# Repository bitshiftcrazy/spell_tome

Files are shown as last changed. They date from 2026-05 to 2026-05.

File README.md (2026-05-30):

# Spell Tome PCB

<p align="center">
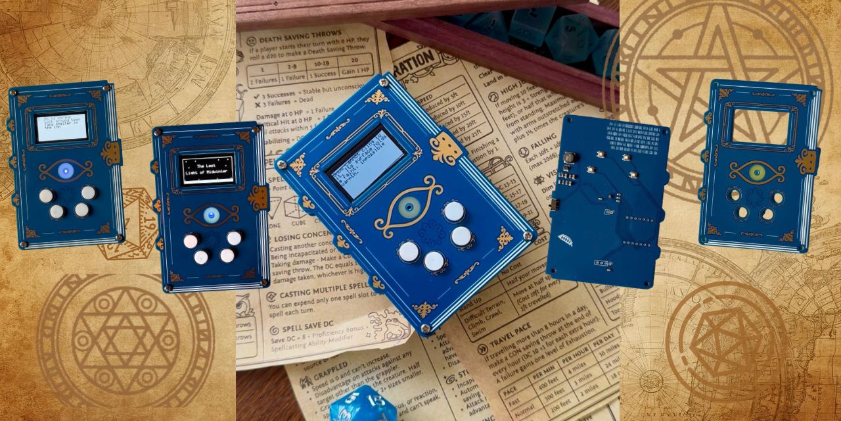
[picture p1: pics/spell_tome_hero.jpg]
  
</p>

A handheld fantasy-themed PCB spell tome designed for tabletop RPGs and other shenanigans.

The Spell Tome is a sandwiched, book-like PCB build consisting of
a functional electronics PCB and a decorative top PCB.
Originally it was designed as a magical artifact for a custom text adventure and small games.

Right now it's evolving into anything that can be done with a tiny OLED and 4 buttons (stay tuned!).

---

## Features

- Handheld layered PCB construction
- Decorative top PCB with silkscreen and copper artwork
- Book-label-style OLED display
- RGB status eye staring at your soul
- Push buttons
- Powered by 2x AAA batteries
- Designed around the Seeed Studio XIAO RP2040
- Custom firmware for text adventures and other games (currently under cleanup, coming soon)

---

## Gallery

<p align="center">
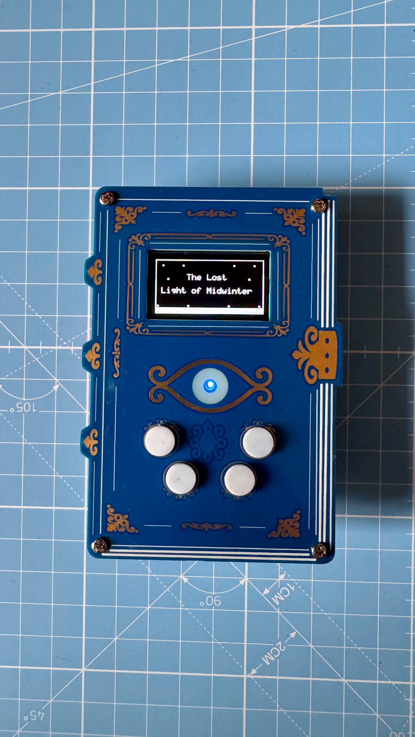
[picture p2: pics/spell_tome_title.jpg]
  
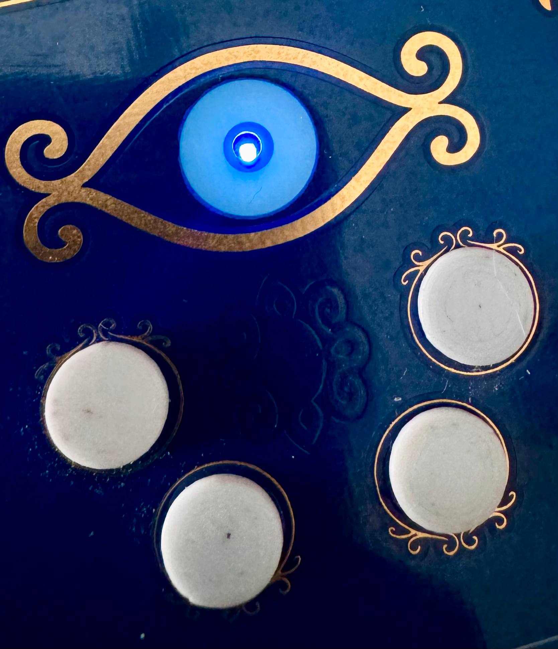
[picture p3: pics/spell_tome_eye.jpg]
  
</p>

<p align="center">
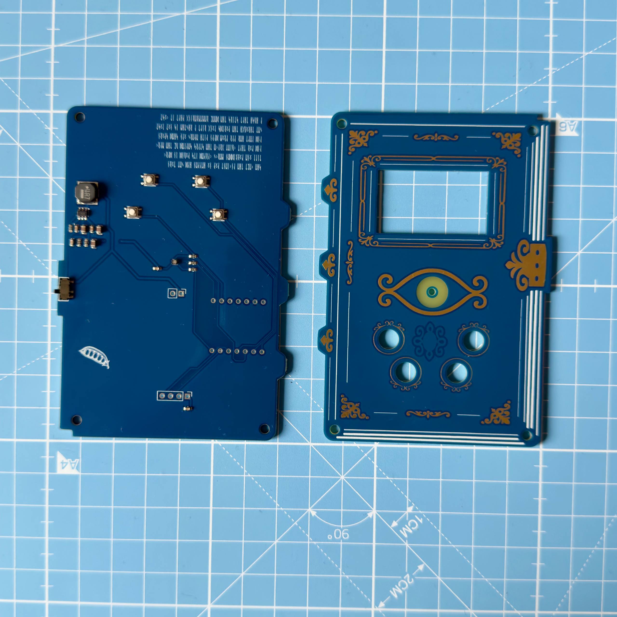
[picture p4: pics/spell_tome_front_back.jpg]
  
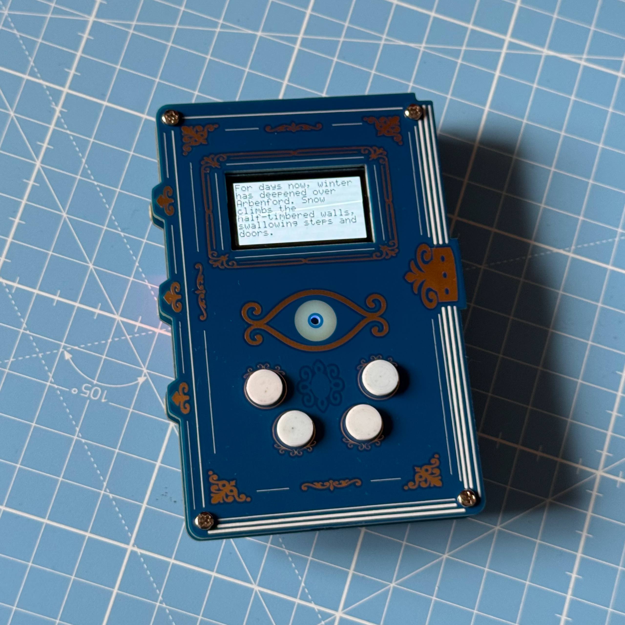
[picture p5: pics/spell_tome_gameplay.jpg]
  
</p>

---

## Hardware Overview

<p align="center">
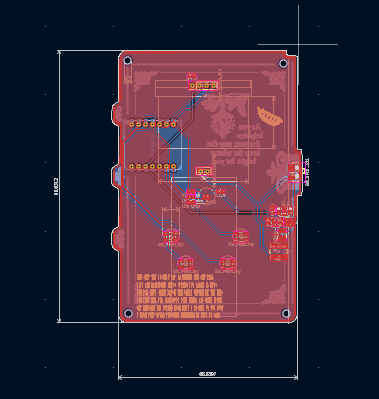
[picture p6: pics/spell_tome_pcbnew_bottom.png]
  
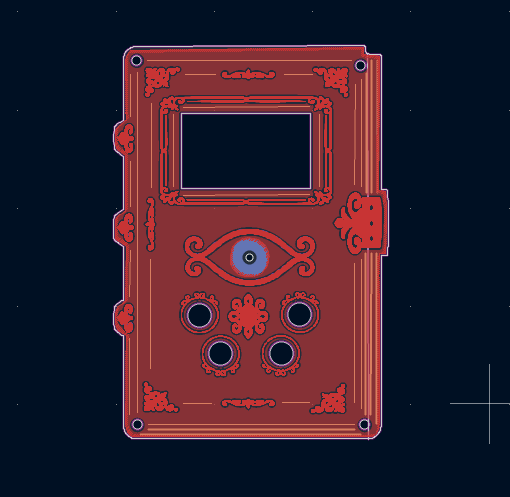
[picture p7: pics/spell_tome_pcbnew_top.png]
  
</p>

The Spell Tome is designed around a Seeed Studio XIAO RP2040 to make it easy to customise, reprogram, and repurpose. It consists of two separate PCBs that together form a small handheld device, no additional case needed.

### Bottom PCB

The bottom PCB holds all the electronics, meaning the schematics only refer to the bottom PCB. Buttons and RGB LED parts are flat so that the handheld stays slim overall.

<p align="center">
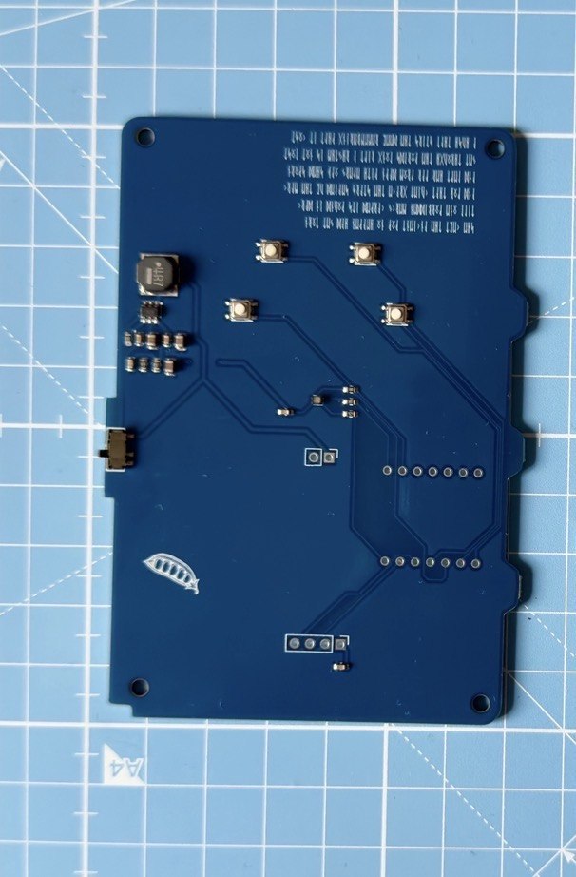
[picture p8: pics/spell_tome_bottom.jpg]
  
</p>

### Top PCB

The top PCB functions as a decorative cover for the handheld. It has an eye-shaped keepout zone so the status LED's light shines through. Very magic. Much wow.

It also has cutouts for 4 3D printed buttons.

<p align="center">
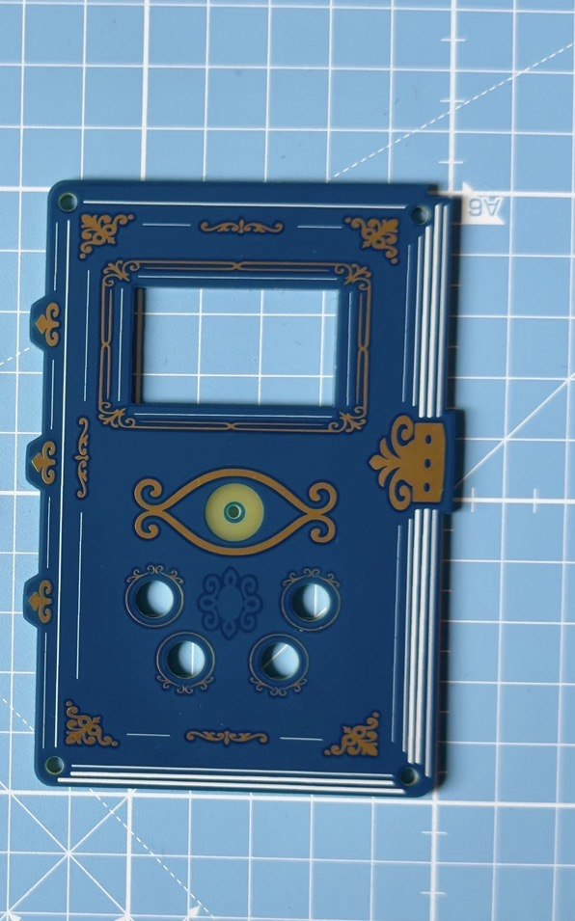
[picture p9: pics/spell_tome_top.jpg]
  
</p>

---

## Main Components

The parts selection is mainly influenced by "I have this at home already" and "I want people to be able to easily assemble and program it":

- Seeed Studio XIAO RP2040 microcontroller
- 1.3" OLED display
- MCP1640 boost converter
- RGB status LED
- 4x tactile push buttons
- Power slide switch
- 2x AAA battery holder
- 4x 3D printed button caps
- 4x spacers and screws (ideally golden, for the vibe)

Of course the project also uses standard components such as
resistors, capacitors, and passive power circuitry. You'll find them and their respective values in the BOM files in:

```text
fabrication/bom/
```

---

## Assembly

<p align="center">
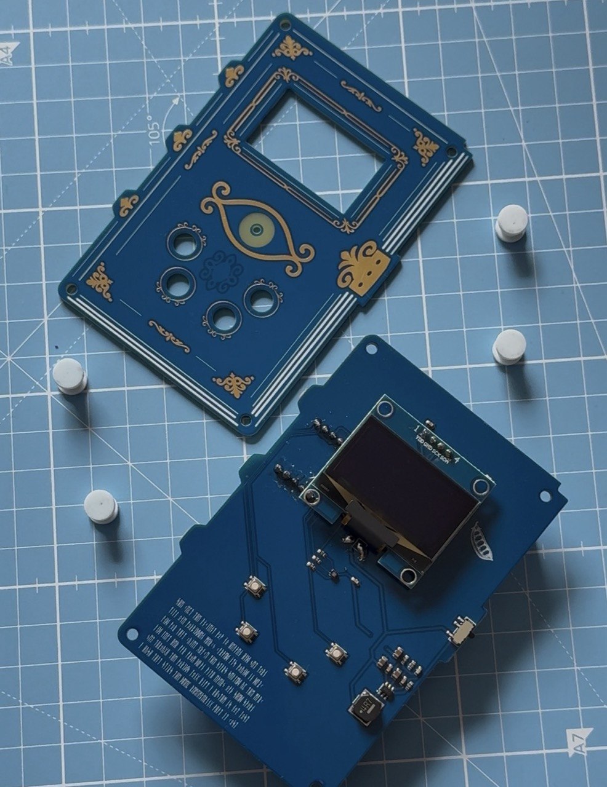
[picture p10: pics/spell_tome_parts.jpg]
  
</p>

### PCB Stackup

Since the Spell Tome uses a layered PCB construction, you'll need to fit these parts together:

1. Bottom electronics PCB
2. Printed button elements
3. Decorative top PCB
4. Battery holder

To assemble the Tome you'll need M2.5 screws and spacers/standoffs (6 mm worked well for me here).

Detailed soldering instructions follow.

Assuming you already soldered the parts:

1. Screw the standoff to the bottom PCB (screw on the outward-facing side, standoff inside)
2. Put the button-shaped button parts through the top PCB's holes and secure them with the little 3D printed rings
3. Put the cover on top of the standoffs on the bottom PCB and test the buttons a little to find a good distance before screwing it on (you can also adjust this later with something pointy)
4. Glue the battery holder to the back where it feels comfortable and make sure to secure the wires with a little glue as well

#### Mechanical Button Parts

3D printable parts are available in:

```text
mechanical/
```

Print the buttons without supports.

### Assembly Notes

- you can find golden screws that pass the vibe check if you look for jewellery screws
- I printed the buttons in white PLA, but it's probably more comfy to use TPU and prettier with something shiny
- depending on how thick you want that thing to be, you can also use longer standoffs and put the batteries between the sandwich layers

---

## Repository Structure

```text
spell_tome/
├── artwork/        # Source artwork and SVG files
├── fabrication/    # BOMs and fabrication outputs
├── libraries/      # Local KiCad symbol and footprint libraries
├── mechanical/     # 3D printable parts
├── pics/           # Images and renders
├── *.kicad_*       # Main KiCad project files
└── README.md
```

---

## Firmware

Firmware was hacked together in one long weekend and is currently under cleanup (guess "a little messy" is fine for personal projects, "wtf even is that" is not ;)) and will be published in this repo soon.

Features:
- the cringiest text adventure you'll ever play
- impractical mini games
- the mysterious blood moon side quest

---

## Fabrication

Gerbers and manufacturing files can be generated directly from the KiCad project files. The current Gerbers are the tested and working version.

Please make sure to regenerate them before sending something to fabrication, I cannot be trusted to remember to do this after every change I make.

Pre-generated fabrication outputs belong and are available in:

```text
fabrication/gerbers/
```

---

## Color inspo

<p align="center">
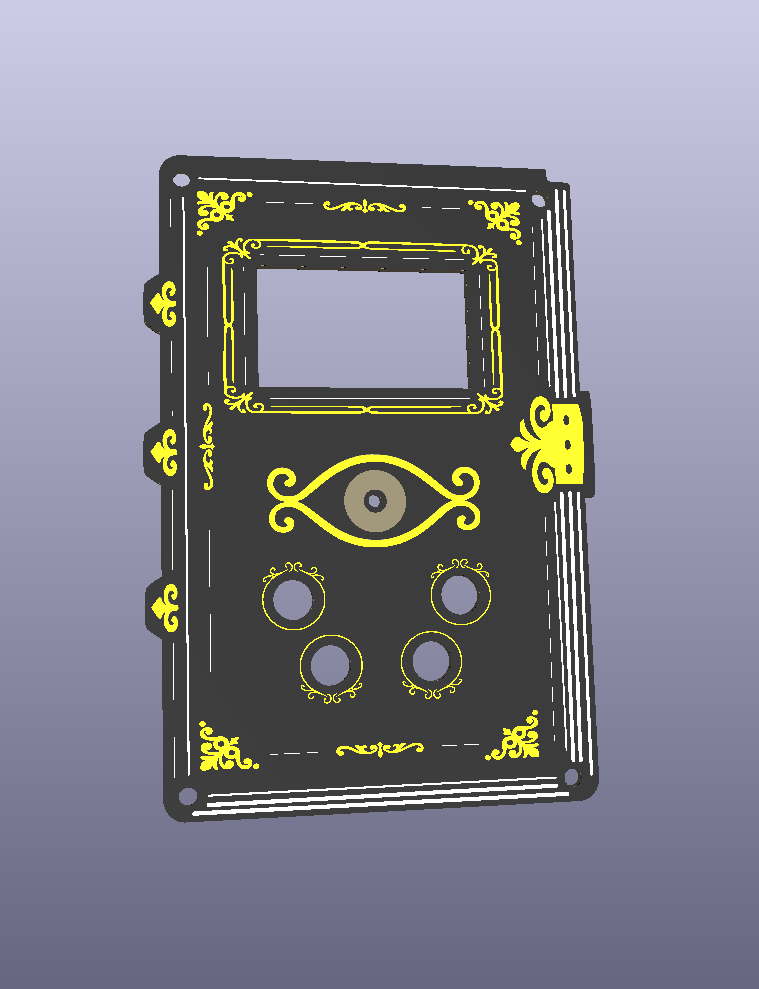
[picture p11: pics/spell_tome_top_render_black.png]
  
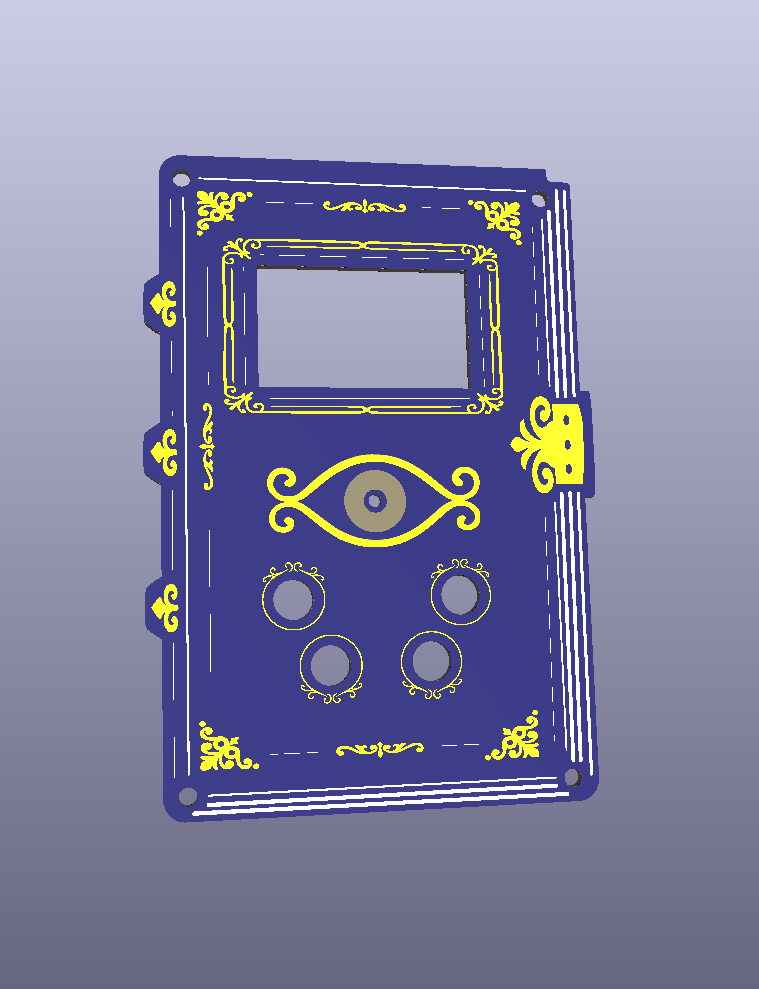
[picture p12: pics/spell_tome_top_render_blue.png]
  
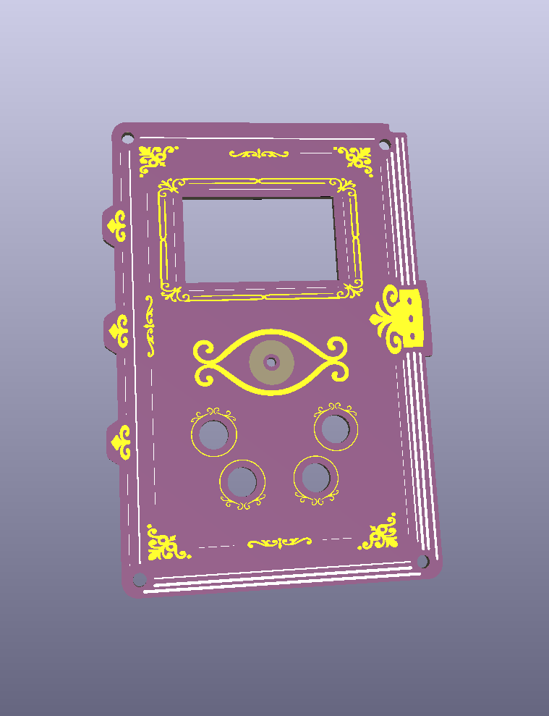
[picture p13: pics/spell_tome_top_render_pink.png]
  
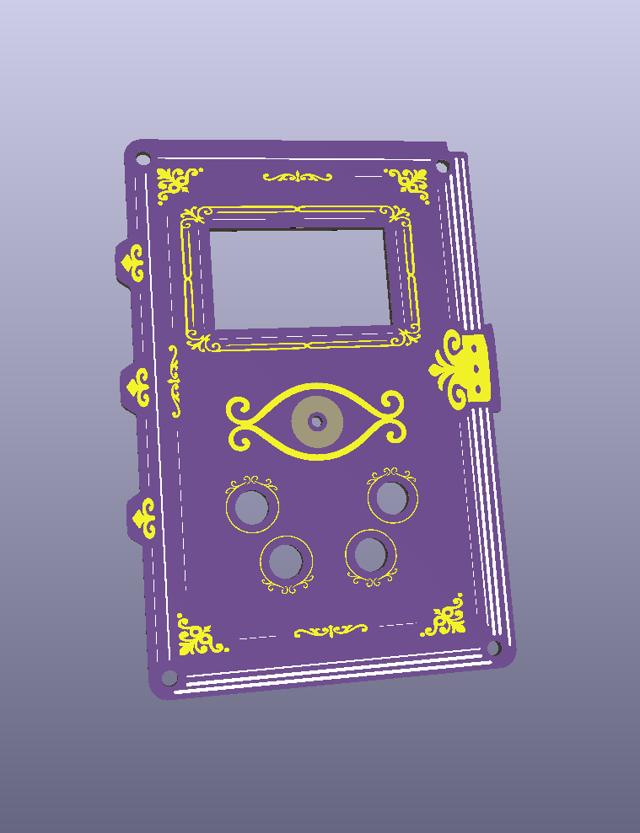
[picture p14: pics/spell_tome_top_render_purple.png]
  
</p>

## Further Reading
- [Hackster: This Open Source RP2040 Development Board Looks Like a Magic Spellbook](https://www.hackster.io/news/this-open-source-rp2040-development-board-looks-like-a-magic-spellbook-52a614f74b81)

## License

Hardware design files are licensed under the CERN Open Hardware Licence
Version 2 - Strongly Reciprocal (CERN-OHL-S-2.0).

See the `LICENSE` file for details.

Copyright (c) 2026 miss.molerat

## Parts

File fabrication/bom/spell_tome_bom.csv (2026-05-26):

Reference | Qty | Value | DNP | Exclude from BOM | Exclude from Board | Footprint | Datasheet | LCSC
C1(CIN)1,C3(COUT)1,C3(COUT)2 | 3 | 10uF |  |  |  | Capacitor_SMD:C_0805_2012Metric | ~ | C15850
C2(CIN_HF)1,C4(COUT_HF)1,C5(C_RGB)1,C7(C_OLED)1 | 4 | 0.1uF |  |  |  | Capacitor_SMD:C_0603_1608Metric | ~ | C14663
C6(Cff)1 | 1 | 47pF |  |  |  | Capacitor_SMD:C_0603_1608Metric | ~ | C94904
D1 | 1 | LED_RABG |  |  |  | tome:LED-ARRAY-SMD_4P-L1.6-W1.5-TL_NH-B1515RGBA | ~ | C2874115
J1 | 1 | Conn_01x04_Pin |  |  |  | Connector_PinHeader_2.54mm:PinHeader_1x04_P2.54mm_Vertical | ~
J2 | 1 | Conn_01x02_Pin |  |  |  | Connector_PinHeader_2.54mm:PinHeader_1x02_P2.54mm_Vertical | ~
L1 | 1 | L |  |  |  | tome:IND-SMD_L6.0-W6.0_NR6028T2R2N | ~
R1(red)1 | 1 | 470 Ohm |  |  |  | Resistor_SMD:R_0603_1608Metric | ~ | C23179
R2(green)1,R3(blue)1 | 2 | 150 Ohm |  |  |  | Resistor_SMD:R_0603_1608Metric | ~ | C22808
R4(R_top)1 | 1 | 680kOhm |  |  |  | Resistor_SMD:R_0603_1608Metric | ~ | C25822
R5(R_bottom)1 | 1 | 390kOhm |  |  |  | Resistor_SMD:R_0603_1608Metric | ~ | C23150
R6 | 1 | R |  |  |  | Resistor_SMD:R_0603_1608Metric | ~ | C25803
SW1,SW3,SW4,SW5 | 4 | SW_Push_my |  |  |  | tome:SW-SMD_4P-L3.4-W3.4-P2.15-LS4.2 | ~ | C596271
SW2 | 1 | SW_SPDT_321 |  |  |  | tome:SW-SMD_SSSS810701 | ~ | C97433
U1 | 1 | XIAO-RP2040-DIP |  |  |  | Seeed Xiao RP2040:XIAO-RP2040-DIP
U2 | 1 | MCP1640x-xCHY |  |  |  | tome:SOT-23-6_L2.9-W1.6-P0.95-LS2.8-BR | http://ww1.microchip.com/downloads/en/DeviceDoc/20002234D.pdf | C44365

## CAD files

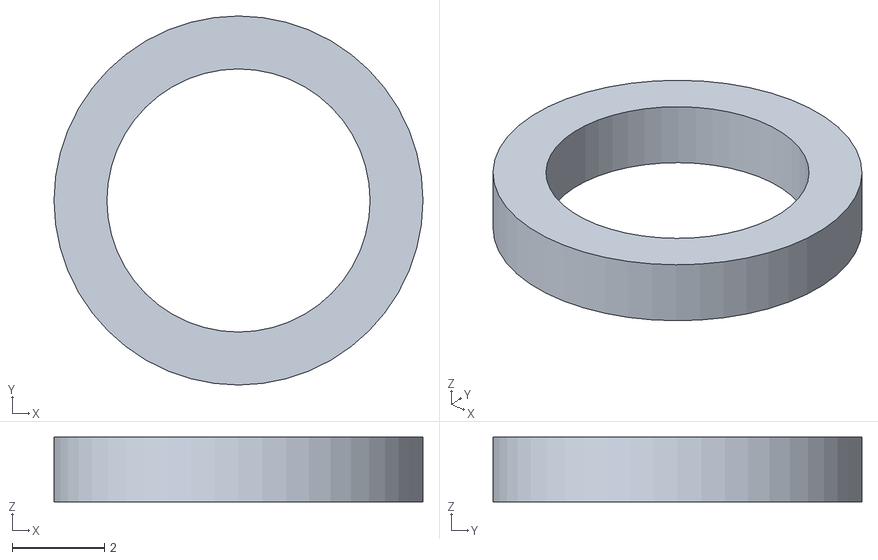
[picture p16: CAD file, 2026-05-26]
mechanical/spell_tome_button.stl
8.00 x 8.00 x 1.40

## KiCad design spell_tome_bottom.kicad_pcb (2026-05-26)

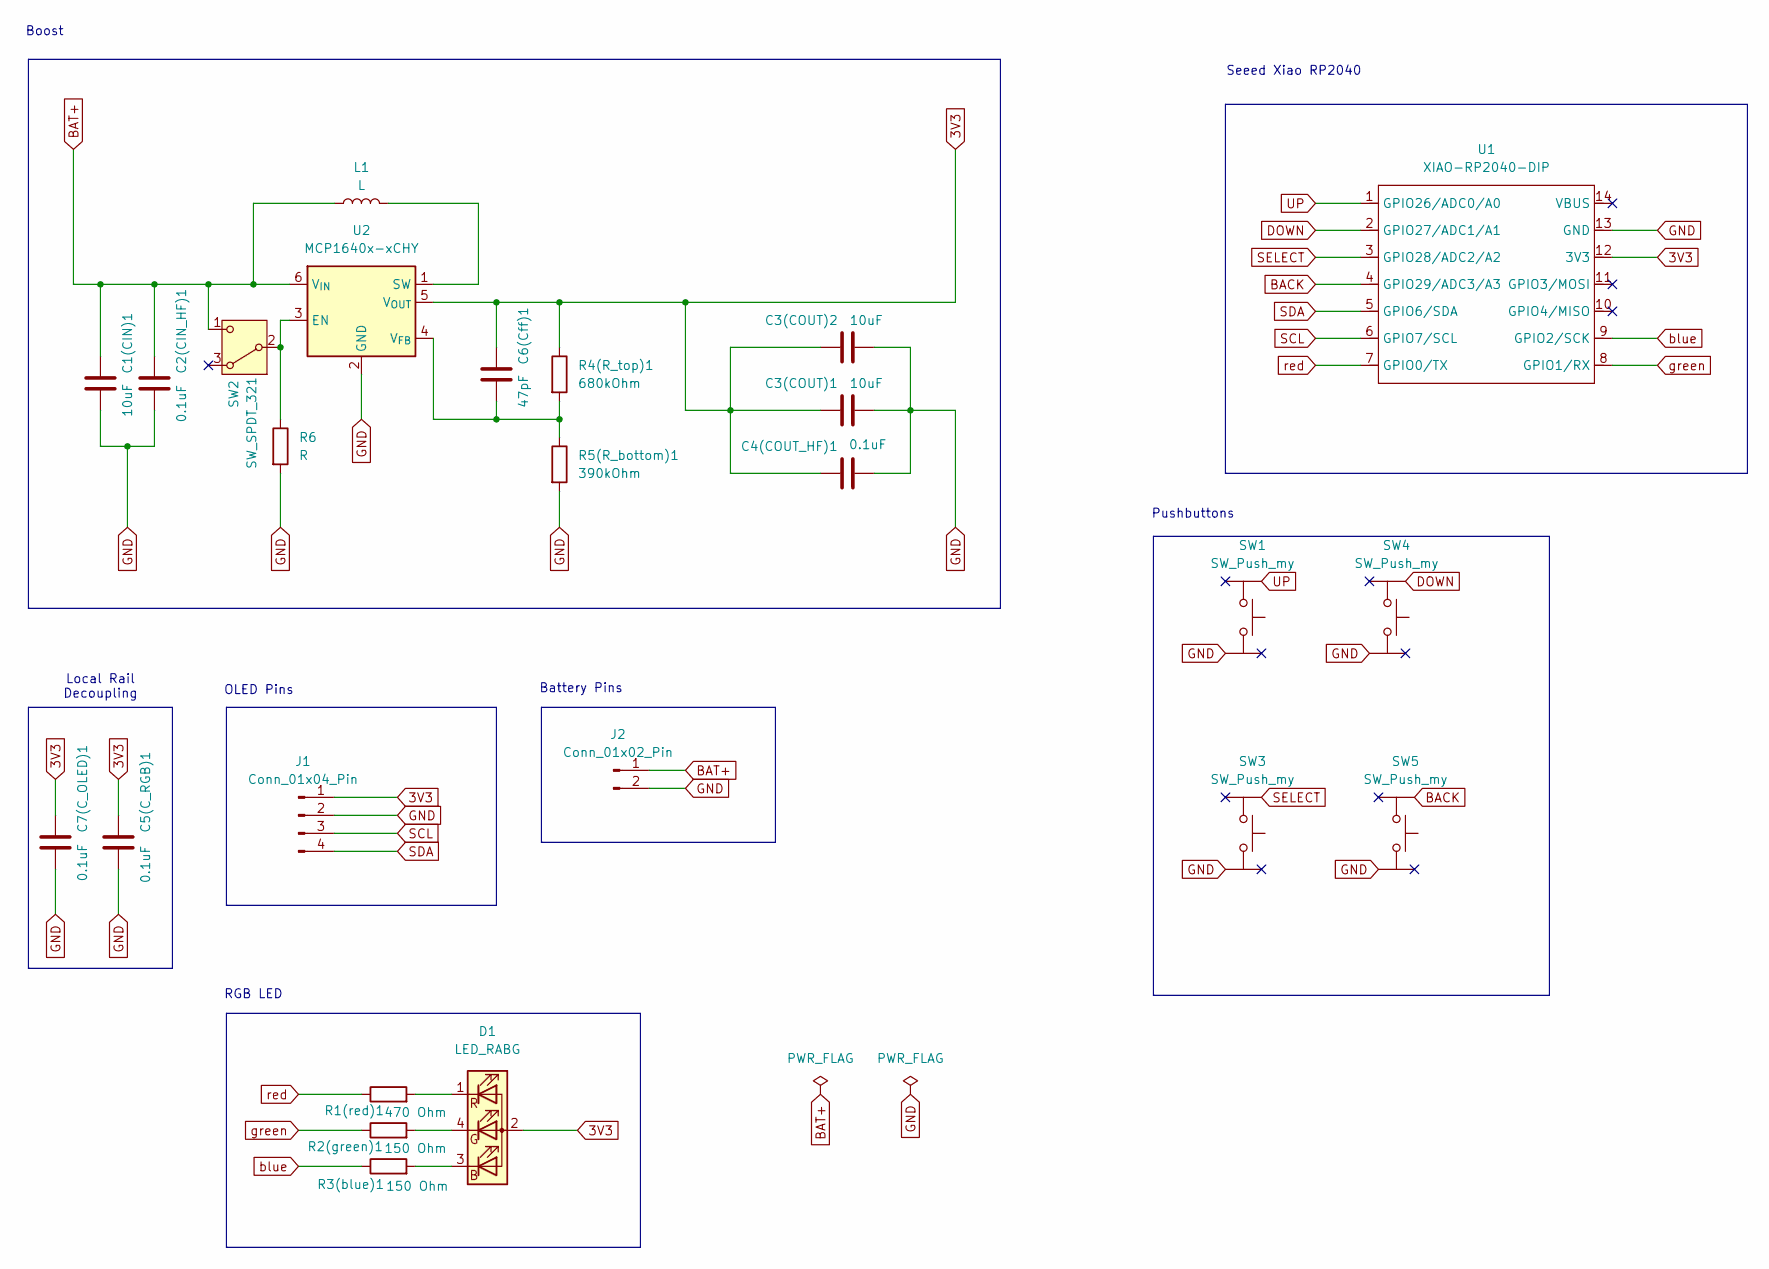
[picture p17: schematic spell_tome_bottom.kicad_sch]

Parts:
C1(CIN)1, C3(COUT)1, C3(COUT)2: 10uF; C_0805_2012Metric; LCSC C15850
C2(CIN_HF)1, C4(COUT_HF)1, C5(C_RGB)1, C7(C_OLED)1: 0.1uF; C_0603_1608Metric; LCSC C14663
C6(Cff)1: 47pF; C_0603_1608Metric; LCSC C94904
D1: LED_RABG; LED-ARRAY-SMD_4P-L1.6-W1.5-TL_NH-B1515RGBA; LCSC C2874115
J1: Conn_01x04_Pin; PinHeader_1x04_P2.54mm_Vertical
J2: Conn_01x02_Pin; PinHeader_1x02_P2.54mm_Vertical
L1: L; IND-SMD_L6.0-W6.0_NR6028T2R2N
R1(red)1: 470 Ohm; R_0603_1608Metric; LCSC C23179
R2(green)1, R3(blue)1: 150 Ohm; R_0603_1608Metric; LCSC C22808
R4(R_top)1: 680kOhm; R_0603_1608Metric; LCSC C25822
R5(R_bottom)1: 390kOhm; R_0603_1608Metric; LCSC C23150
R6: R; R_0603_1608Metric; LCSC C25803
SW1, SW3, SW4, SW5: SW_Push_my; SW-SMD_4P-L3.4-W3.4-P2.15-LS4.2; LCSC C596271
SW2: SW_SPDT_321; SW-SMD_SSSS810701; LCSC C97433
U1: XIAO-RP2040-DIP
U2: MCP1640x-xCHY; SOT-23-6_L2.9-W1.6-P0.95-LS2.8-BR; LCSC C44365

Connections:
3V3: C3(COUT)1.1, C3(COUT)2.1, C4(COUT_HF)1.1, C5(C_RGB)1.1, C6(Cff)1.1, C7(C_OLED)1.1, D1.2 (A), J1.1, R4(R_top)1.1, U1.12 (3V3), U2.5 (V_{OUT})
BACK: SW5.1, U1.4 (GPIO29/ADC3/A3)
BAT+: C1(CIN)1.1, C2(CIN_HF)1.1, J2.1, L1.1, SW2.1 (C), U2.6 (V_{IN})
DOWN: SW4.1, U1.2 (GPIO27/ADC1/A1)
GND: C1(CIN)1.2, C2(CIN_HF)1.2, C3(COUT)1.2, C3(COUT)2.2, C4(COUT_HF)1.2, C5(C_RGB)1.2, C7(C_OLED)1.2, J1.2, J2.2, R5(R_bottom)1.2, R6.2, SW1.4, SW3.4, SW4.4, SW5.4, U1.13 (GND), U2.2 (GND)
unnamed: D1.3 (BK), R3(blue)1.2
unnamed: D1.4 (GK), R2(green)1.2
unnamed: D1.1 (RK), R1(red)1.2
unnamed: R6.1, SW2.2 (B), U2.3 (EN)
unnamed: L1.2, U2.1 (SW)
unnamed: C6(Cff)1.2, R4(R_top)1.2, R5(R_bottom)1.1, U2.4 (V_{FB})
SCL: J1.3, U1.6 (GPIO7/SCL)
SDA: J1.4, U1.5 (GPIO6/SDA)
SELECT: SW3.1, U1.3 (GPIO28/ADC2/A2)
UP: SW1.1, U1.1 (GPIO26/ADC0/A0)
blue: R3(blue)1.1, U1.9 (GPIO2/SCK)
green: R2(green)1.1, U1.8 (GPIO1/RX)
red: R1(red)1.1, U1.7 (GPIO0/TX)

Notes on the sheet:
OLED Pins
RGB LED
Battery Pins
Pushbuttons
Boost
Seeed Xiao RP2040
Local Rail Decoupling

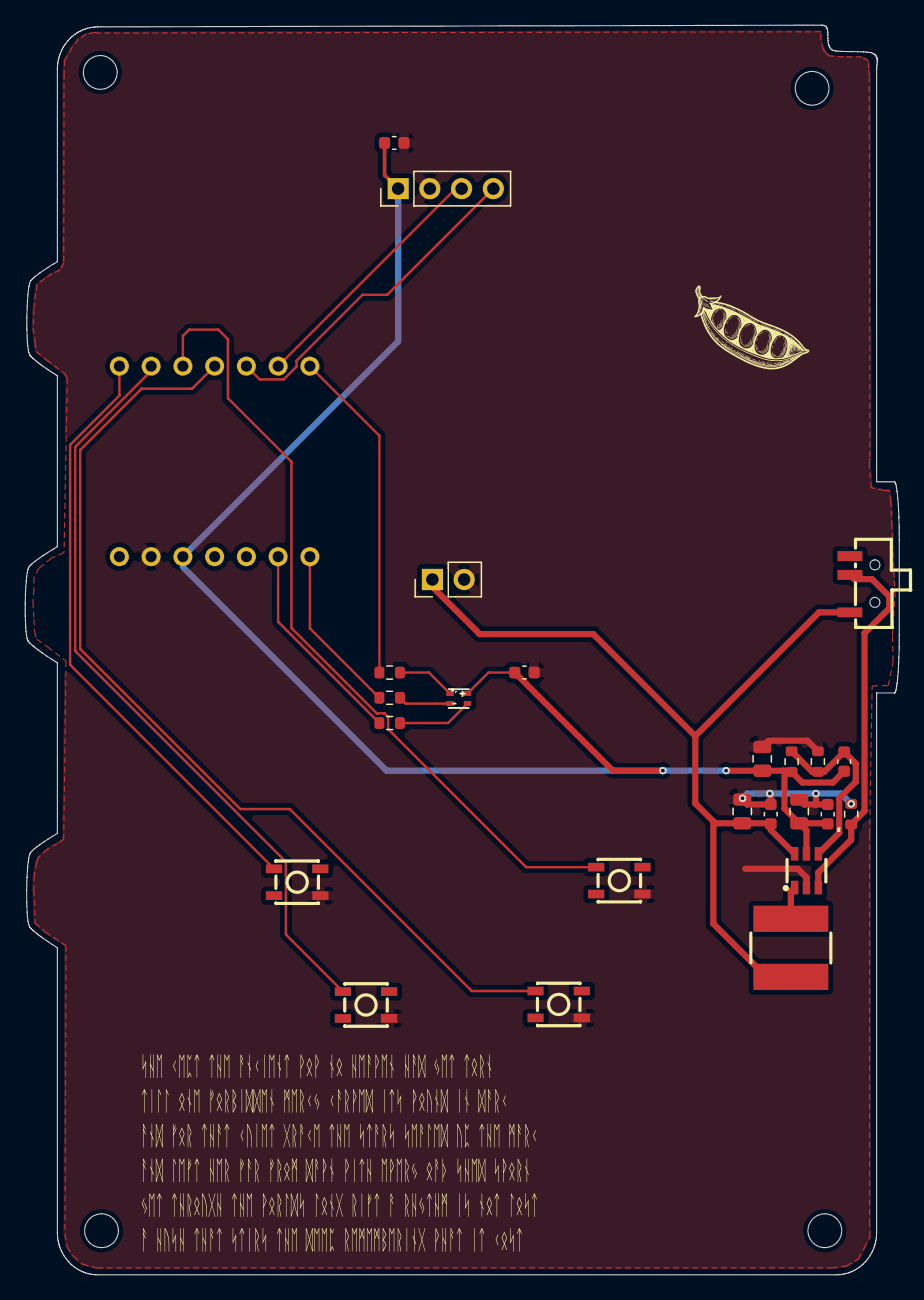
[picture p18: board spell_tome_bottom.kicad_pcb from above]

Board: 2 copper layers, 69.9 x 100.0 mm, 25 parts (1 on the bottom side), 18 nets.
